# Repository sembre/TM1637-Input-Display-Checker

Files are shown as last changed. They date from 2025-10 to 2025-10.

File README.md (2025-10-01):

# TM1637 Input Display Checker

## 📌 Deskripsi (Bahasa Indonesia)

Proyek ini berfungsi untuk membaca status dari sejumlah pin digital pada board **Arduino** dan menampilkan nomor pin yang **aktif (terhubung ke GND)** ke **7-segmen display TM1637**.  
Selain itu, nomor pin yang aktif juga akan ditampilkan pada **Serial Monitor**.

🔌 **Fungsi utama:**
- Memeriksa banyak pin input digital secara otomatis.
- Menampilkan nomor pin yang aktif pada **TM1637 7-segmen**.
- Mengirim informasi pin aktif ke **Serial Monitor**.
- Menggunakan **INPUT_PULLUP** sehingga tidak memerlukan resistor eksternal.

---

## 📘 Description (English)

This project reads the status of multiple digital input pins on an **Arduino** board and displays the number of the pin that is **active (connected to GND)** on a **TM1637 7-segment display**.  
Additionally, the active pin number is also printed to the **Serial Monitor**.

🔌 **Main features:**
- Automatically scans multiple digital input pins.
- Displays the active pin number on a **TM1637 display**.
- Sends active pin info to the **Serial Monitor**.
- Uses **INPUT_PULLUP** to eliminate the need for external resistors.

---

## 🛠️ Hardware Requirements

- Arduino Mega / Uno  
- TM1637 7-segment display module  
- Jumper cables  
- GND switch or test pins  

---

## 🔌 Wiring (TM1637)

| TM1637 Pin | Arduino Pin |
|---|---|
| CLK | A0 |
| DIO | A1 |
| VCC | 5V |
| GND | GND |

> ⚠️ Setiap pin input menggunakan `INPUT_PULLUP`, jadi cukup hubungkan ke **GND** untuk membacanya sebagai aktif.

---

## 📁 File

- `cek_pin_MAX-37.ino` – File utama Arduino yang menjalankan logika pembacaan pin dan tampilan TM1637.

---

## ▶️ Cara Menggunakan (Usage)

1. Sambungkan TM1637 ke Arduino sesuai tabel wiring di atas.  
2. Upload kode `cek_pin_MAX-37.ino` ke Arduino menggunakan Arduino IDE.  
3. Buka **Serial Monitor** dengan baud rate `9600`.  
4. Hubungkan salah satu pin input ke **GND**.  
5. Nomor pin aktif akan muncul di **display TM1637** dan **Serial Monitor**.

---

## 📜 Lisensi (License)

**Creative Commons Attribution 4.0 International (CC BY 4.0)**  
🔗 [https://creativecommons.org/licenses/by/4.0/](https://creativecommons.org/licenses/by/4.0/)

📌 Anda **bebas** menggunakan, membagikan, memodifikasi, dan mendistribusikan kode ini — termasuk untuk tujuan komersial — **selama mencantumkan atribusi** kepada penulis asli.

📎 **Atribusi wajib:**  
Penulis: [AGUS FITRIYANTO](https://github.com/sembre)  
GitHub: [https://github.com/sembre](https://github.com/sembre)

---

## 🤝 Kontribusi (Contributing)

Pull request dan kontribusi sangat diterima!  
Jika Anda menemukan bug atau ingin menambahkan fitur baru, silakan buat *issue* atau kirim *PR* di repository ini.

---

## 📧 Kontak (Contact)

📍 Author: **AGUS FITRIYANTO**  
🔗 GitHub: [https://github.com/sembre](https://github.com/sembre)  

---
## 🦅 File Eagle (Desain PCB/Schematics)

Jika Anda ingin membuat PCB atau melihat skematik, tersedia file Eagle (.sch dan .brd):

- `cek pin 37.sch` – Skematik rangkaian Eagle
- `cek pin 37.brd` – File layout PCB Eagle

### Cara Menggunakan File Eagle

1. Buka file `.sch` atau `.brd` menggunakan **Autodesk Eagle** versi terbaru atau yang kompatibel.
2. Anda dapat memodifikasi desain sesuai kebutuhan, melakukan routing, atau langsung mencetak layout untuk produksi PCB.
3. File ini dapat digunakan sebagai referensi wiring atau untuk pembuatan PCB custom.

> Jika Anda belum memiliki Eagle, Anda bisa mengunduhnya secara gratis untuk penggunaan hobi dari [Autodesk Eagle Official](https://www.autodesk.com/products/eagle/free-download).

---

✨ **Happy coding and hacking!**

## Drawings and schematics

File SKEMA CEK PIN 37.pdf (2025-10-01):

# Skema CEK PIN 37

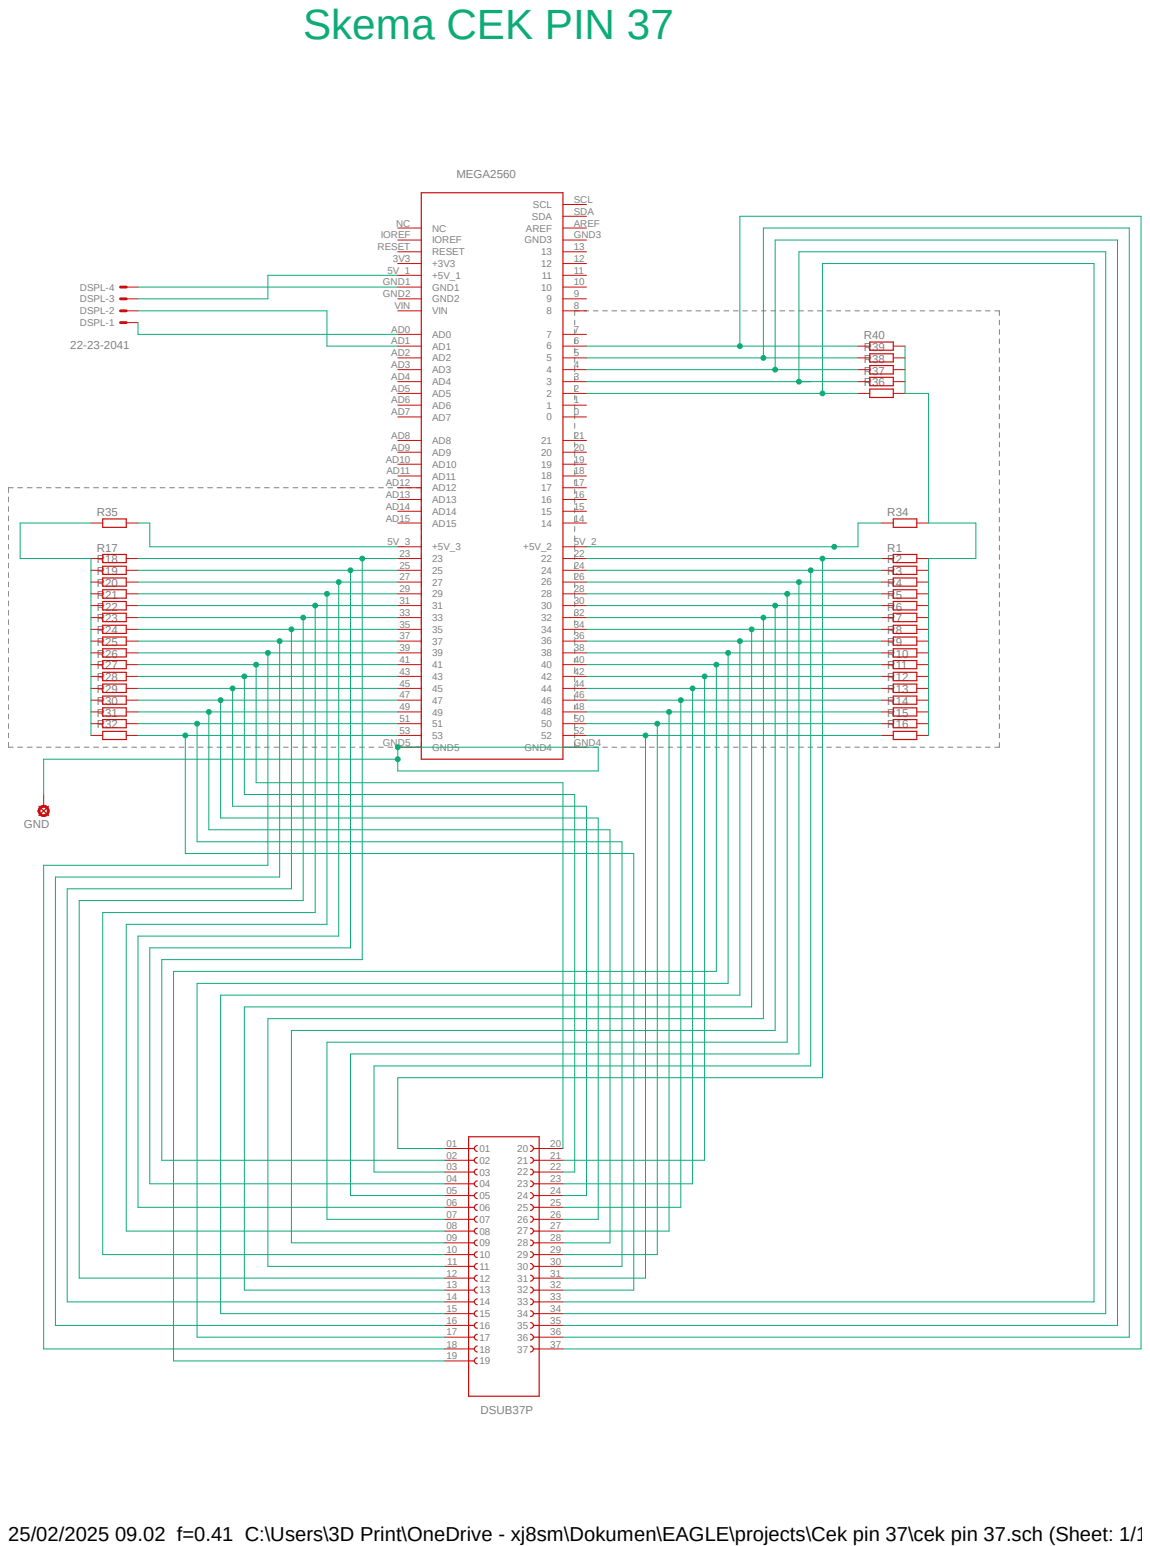
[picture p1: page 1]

AD1 | 6
AD2 | 5 | | R39
AD3 | 4 | R38
AD4 | 3 | R37
AD5 | 2 | R36

25/02/2025 09.02 f=0.41 C:\Users\3D Print\OneDrive - xj8sm\Dokumen\EAGLE\projects\Cek pin 37\cek pin 37.sch (Sheet: 1/1)

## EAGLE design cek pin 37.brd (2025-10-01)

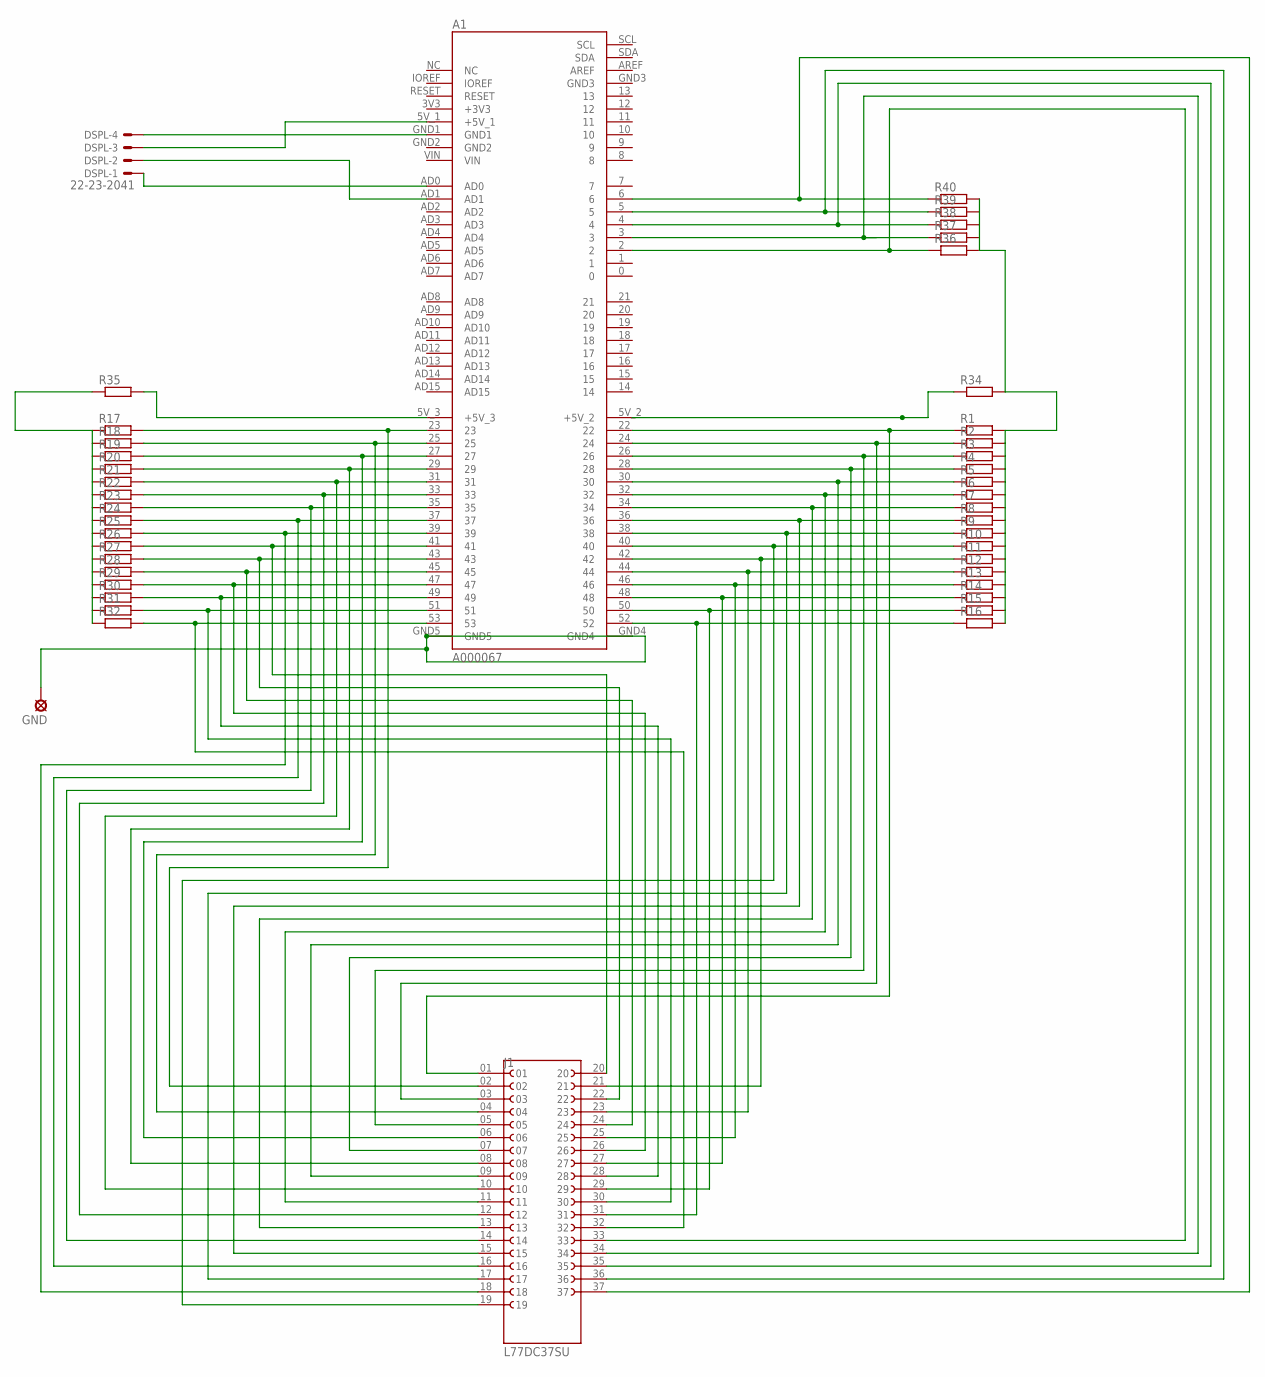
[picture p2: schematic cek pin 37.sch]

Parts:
A1: A000067; ARDUINO_A000067
DSPL: 22-23-2041
GND: LSP10
J1: L77DC37SU; AMPHENOL_L77DC37SU
R1, R2, R3, R4, R5, R6, R7, R8, R9, R10, R11, R12, R13, R14, R15, R16, R17, R18, R19, R20, R21, R22, R23, R24, R25, R26, R27, R28, R29, R30, R31, R32, R34, R35, R36, R37, R38, R39, R40: R-EU_0207/12; 0207/12

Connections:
unnamed: A1.23, J1.02, R17.2
unnamed: A1.25, J1.04, R18.2
unnamed: A1.27, J1.06, R19.2
unnamed: A1.29, J1.08, R20.2
unnamed: A1.31, J1.10, R21.2
unnamed: A1.33, J1.12, R22.2
unnamed: A1.35, J1.14, R23.2
unnamed: A1.37, J1.16, R24.2
unnamed: A1.39, J1.18, R25.2
unnamed: A1.41, J1.20, R26.2
unnamed: A1.43, J1.22, R27.2
unnamed: A1.45, J1.24, R28.2
unnamed: A1.47, J1.26, R29.2
unnamed: A1.49, J1.28, R30.2
unnamed: A1.51, J1.30, R31.2
unnamed: A1.53, J1.32, R32.2
unnamed: A1.22, J1.01, R1.1
unnamed: A1.24, J1.03, R2.1
unnamed: A1.26, J1.05, R3.1
unnamed: A1.28, J1.07, R4.1
unnamed: A1.30, J1.09, R5.1
unnamed: A1.32, J1.11, R6.1
unnamed: A1.34, J1.13, R7.1
unnamed: A1.36, J1.15, R8.1
unnamed: A1.5V_1 (+5V_1), DSPL.3
unnamed: A1.GND1, DSPL.4
unnamed: A1.AD1, DSPL.2
unnamed: A1.44, J1.23, R12.1
unnamed: A1.46, J1.25, R13.1
unnamed: A1.48, J1.27, R14.1
unnamed: A1.50, J1.29, R15.1
unnamed: A1.52, J1.31, R16.1
unnamed: A1.38, J1.17, R9.1
unnamed: A1.5V_3 (+5V_3), R35.2
unnamed: A1.2, J1.33, R36.1
unnamed: A1.AD0, DSPL.1
unnamed: A1.4, J1.35, R38.1
unnamed: A1.5, J1.36, R39.1
unnamed: A1.6, J1.37, R40.1
unnamed: R1.2, R2.2, R3.2, R4.2, R5.2, R6.2, R7.2, R8.2, R9.2, R10.2, R11.2, R12.2, R13.2, R14.2, R15.2, R16.2, R34.2, R36.2, R37.2, R38.2, R39.2, R40.2
unnamed: R17.1, R18.1, R19.1, R20.1, R21.1, R22.1, R23.1, R24.1, R25.1, R26.1, R27.1, R28.1, R29.1, R30.1, R31.1, R32.1, R35.1
unnamed: A1.5V_2 (+5V_2), R34.1
unnamed: A1.40, J1.19, R10.1
unnamed: A1.42, J1.21, R11.1
unnamed: A1.GND4, A1.GND5, GND.MP
unnamed: A1.3, J1.34, R37.1

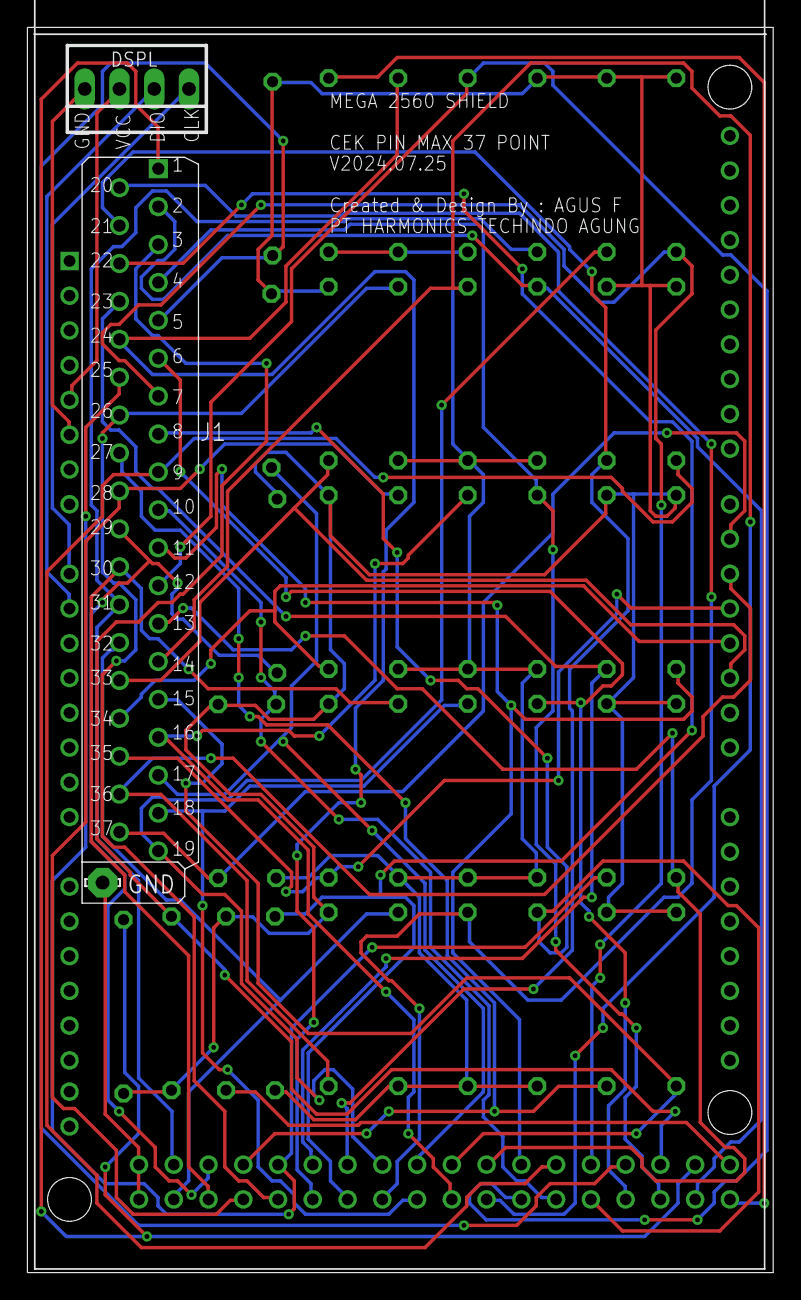
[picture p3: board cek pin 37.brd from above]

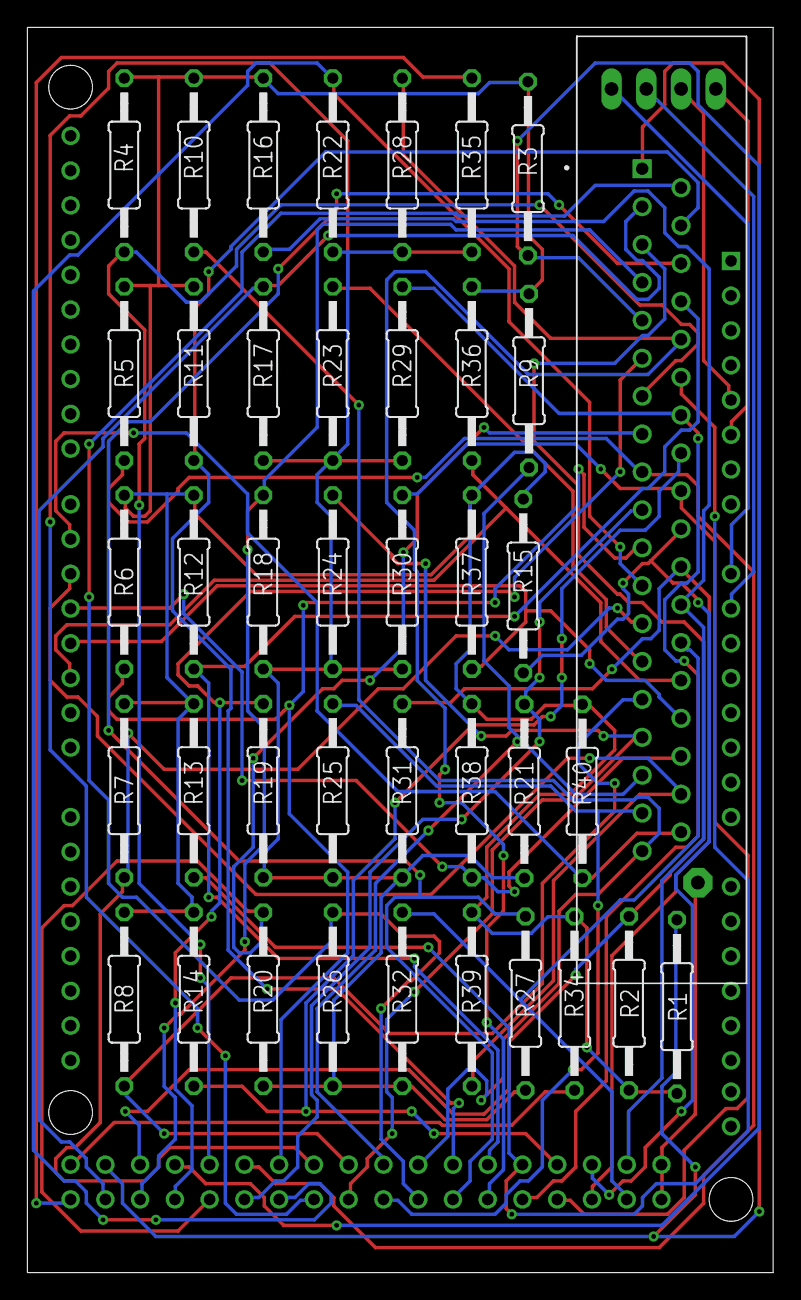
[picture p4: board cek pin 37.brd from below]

Board: 2 copper layers, 54.5 x 91.0 mm, 43 parts (40 on the bottom side), 46 nets.

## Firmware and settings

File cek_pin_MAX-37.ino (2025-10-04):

/*
  ------------------------------------------------------------------------
  Project   : TM1637 Input Display Checker
  Date      : 2024-08-09
  Author    : AGUS FITRIYANTO
  GitHub    : https://github.com/sembre
  License   : Creative Commons Attribution 4.0 International (CC BY 4.0)
  License URL: https://creativecommons.org/licenses/by/4.0/

  ------------------------------------------------------------------------
  🇮🇩 Bahasa Indonesia:
  Deskripsi :
  Kode ini membaca status dari sejumlah pin digital pada Arduino dan
  menampilkan nomor pin yang aktif (terhubung ke GND) pada display
  7-segmen TM1637. Selain itu, nomor tersebut juga akan ditampilkan
  pada Serial Monitor.

  Hak Cipta & Lisensi:
  - Anda bebas menggunakan, membagikan, memodifikasi, dan mendistribusikan
    ulang kode ini untuk keperluan apa pun, termasuk komersial.
  - Syaratnya: Anda **wajib memberikan atribusi yang sesuai** kepada penulis
    asli (AGUS FITRIYANTO) dan menyertakan pernyataan lisensi ini.
  - Detail lisensi dapat dibaca di URL di atas.
  - Untuk update atau versi terbaru, kunjungi GitHub: https://github.com/sembre

  ------------------------------------------------------------------------
  🇬🇧 English Version:
  Description:
  This code reads the status of multiple digital pins on the Arduino and
  displays the active pin number (connected to GND) on a TM1637 7-segment
  display. The pin number is also printed on the Serial Monitor.

  Copyright & License:
  - You are free to use, share, modify, and redistribute this code for any
    purpose, including commercial use.
  - Condition: You **must give appropriate credit** to the original author
    (AGUS FITRIYANTO) and include this license statement.
  - For more details, please visit the license URL above.
  - For updates or the latest version, visit GitHub: https://github.com/sembre
  ------------------------------------------------------------------------
*/

// 2024-08-09 add serial monitor
// 2025-10-03 add boot counter with EEPROM and device lock

#include <TM1637Display.h>
#include <EEPROM.h>

// Konfigurasi pin CLK dan DIO pada modul TM1637
#define CLK_PIN A0
#define DIO_PIN A1

// Inisialisasi objek TM1637 dengan pin CLK dan DIO
TM1637Display tm1637(CLK_PIN, DIO_PIN);

// Konstanta untuk boot counter
#define EEPROM_BOOT_ADDRESS 0 // Alamat EEPROM untuk menyimpan boot counter
#define MAX_BOOT_COUNT 7000   // Maksimal boot count sebelum terkunci
#define MAGIC_NUMBER 0xAB     // Magic number untuk validasi EEPROM

// Variabel global
unsigned int bootCount = 0;
bool deviceLocked = false;

// Custom segments untuk menampilkan "dIE" pada TM1637
const uint8_t dieSegments[] = {
    0x5E, // d
    0x30, // I
    0x79  // E
};

// Deklarasi pin secara individu
const int pins[] = {
    22, 23, 24, 25, 26, 27, 28, 29, 30, 31,
    32, 33, 34, 35, 36, 37, 38, 39, 40, 41,
    42, 43, 44, 45, 46, 47, 48, 49, 50, 51,
    52, 53,
    2, 3, 4, 5, 6};

// Fungsi untuk membaca boot count dari EEPROM
unsigned int readBootCount()
{
  unsigned int count = 0;

  // Cek magic number untuk validasi
  if (EEPROM.read(EEPROM_BOOT_ADDRESS + 4) != MAGIC_NUMBER)
  {
    // Jika magic number tidak cocok, inisialisasi EEPROM
    writeBootCount(0);
    return 0;
  }

  // Baca boot count (4 bytes)
  count = (unsigned int)EEPROM.read(EEPROM_BOOT_ADDRESS) |
          ((unsigned int)EEPROM.read(EEPROM_BOOT_ADDRESS + 1) << 8) |
          ((unsigned int)EEPROM.read(EEPROM_BOOT_ADDRESS + 2) << 16) |
          ((unsigned int)EEPROM.read(EEPROM_BOOT_ADDRESS + 3) << 24);

  return count;
}

// Fungsi untuk menulis boot count ke EEPROM
void writeBootCount(unsigned int count)
{
  // Tulis boot count (4 bytes)
  EEPROM.write(EEPROM_BOOT_ADDRESS, count & 0xFF);
  EEPROM.write(EEPROM_BOOT_ADDRESS + 1, (count >> 8) & 0xFF);
  EEPROM.write(EEPROM_BOOT_ADDRESS + 2, (count >> 16) & 0xFF);
  EEPROM.write(EEPROM_BOOT_ADDRESS + 3, (count >> 24) & 0xFF);

  // Tulis magic number untuk validasi
  EEPROM.write(EEPROM_BOOT_ADDRESS + 4, MAGIC_NUMBER);
}

// Fungsi untuk menampilkan "dIE" pada TM1637
void showDieMessage()
{
  tm1637.setSegments(dieSegments, 3, 1); // Tampilkan "dIE" mulai dari posisi 1
}

// Fungsi untuk increment boot count
void incrementBootCount()
{
  bootCount++;
  writeBootCount(bootCount);

  Serial.print("Boot count: ");
  Serial.print(bootCount);
  Serial.print("/");
  Serial.println(MAX_BOOT_COUNT);

  if (bootCount >= MAX_BOOT_COUNT)
  {
    deviceLocked = true;
    Serial.println("DEVICE LOCKED! Maximum boot count reached.");
  }
}

void setup()
{
  // Inisialisasi TM1637
  tm1637.setBrightness(7); // Set brightness level (0 - 7)

  // Inisialisasi Serial Monitor
  Serial.begin(9600);

  // Baca boot count dari EEPROM
  bootCount = readBootCount();

  // Increment boot count dan cek apakah device terkunci
  incrementBootCount();

  // Jika device terkunci, tampilkan "dIE" dan hentikan eksekusi
  if (deviceLocked)
  {
    showDieMessage();
    Serial.println("Device is permanently locked. Showing 'dIE' message.");
    while (1)
    {
      // Loop tak terbatas - device terkunci
      delay(1000);
    }
  }

  // Deklarasi pin sebagai INPUT_PULLUP agar pin terbaca HIGH saat tidak tersambung ke GND
  for (int i = 0; i < sizeof(pins) / sizeof(pins[0]); i++)
  {
    pinMode(pins[i], INPUT_PULLUP);
  }

  Serial.println("Device initialized successfully.");
  Serial.println("Pin checker is ready.");
}

void loop()
{
  // Jika device terkunci, hanya tampilkan "dIE" dan tidak berfungsi
  if (deviceLocked)
  {
    showDieMessage();
    delay(1000);
    return;
  }

  // Cek setiap pin
  for (int i = 0; i < sizeof(pins) / sizeof(pins[0]); i++)
  {
    if (digitalRead(pins[i]) == LOW)
    {
      // Jika pin terhubung ke GND, tampilkan angka pada TM1637 display
      int valueToShow = i + 1; // Start numbering from 1
      tm1637.showNumberDecEx(valueToShow);

      // Tampilkan angka juga di Serial Monitor
      Serial.print("Pin ");
      Serial.print(pins[i]);
      Serial.print(" connected, displaying number: ");
      Serial.println(valueToShow);

      delay(1000);    // Display for 1 second
      tm1637.clear(); // Clear the display after showing
      break;          // Exit loop after detecting the first active pin
    }
  }
}

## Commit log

2025-10-01 Enhance README with comprehensive project details
    Updated README to include detailed project description, features, hardware requirements, wiring instructions, usage steps, license information, contribution guidelines, and contact details.
2025-10-01 Update file name in README for Arduino code
2025-10-04 Implement boot counter and device lock features
    Added boot counter functionality with EEPROM storage and device lock feature. Updated code to display 'dIE' message when the maximum boot count is reached.
